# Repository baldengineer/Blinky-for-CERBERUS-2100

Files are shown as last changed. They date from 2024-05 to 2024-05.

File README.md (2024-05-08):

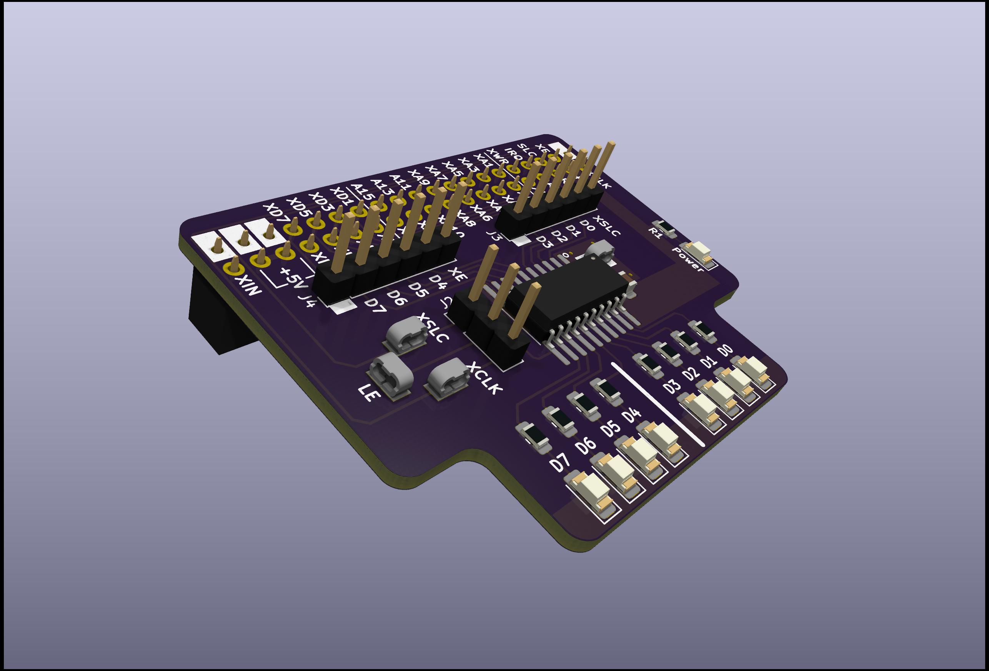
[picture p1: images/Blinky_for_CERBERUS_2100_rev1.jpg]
Blinky Render


## Blinky for CERBERUS 2100
Simple board to plug into a [CERBERUS 2100](https://www.thebyteattic.com/p/cerberus-2100.html) and display blinky patterns. It uses a transparent latch (74HVC573) to display the 8-bit data bus on individual LEDs. You can select between the `XCLK` or `XSLC` to drive the display.

The idea is that `XCLK` would continously update with whatever values are on the data bus. Using `XSLC` should only update after a write occurs (but the timing might be off?).

## Future ideas
I may implement a version with a PLD to experiement with programmable logic. 

## Status
Sent rev 1 to the fab. I realize after that I did not provide an easy way to enable the `XE` signal, which turns on the buffers on the CERBERUS 2100. However, there are pads to bodge it.

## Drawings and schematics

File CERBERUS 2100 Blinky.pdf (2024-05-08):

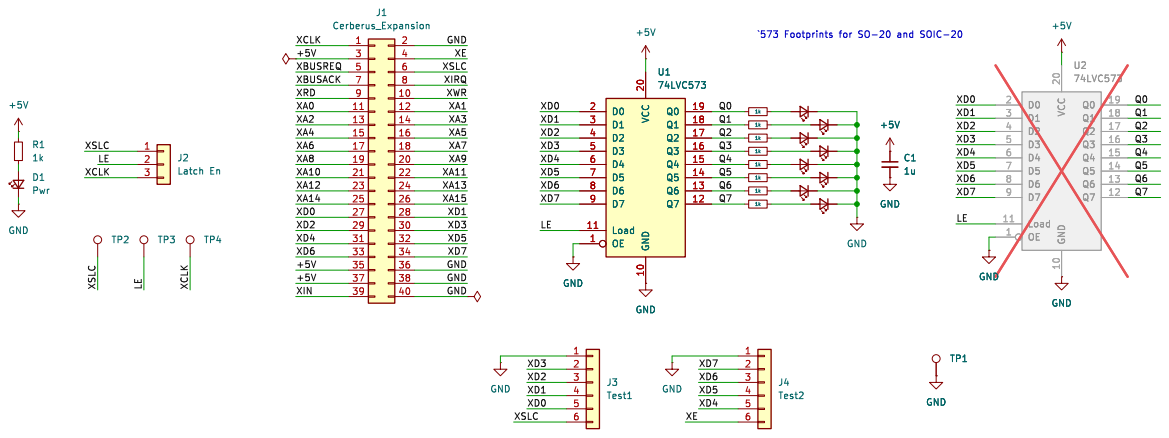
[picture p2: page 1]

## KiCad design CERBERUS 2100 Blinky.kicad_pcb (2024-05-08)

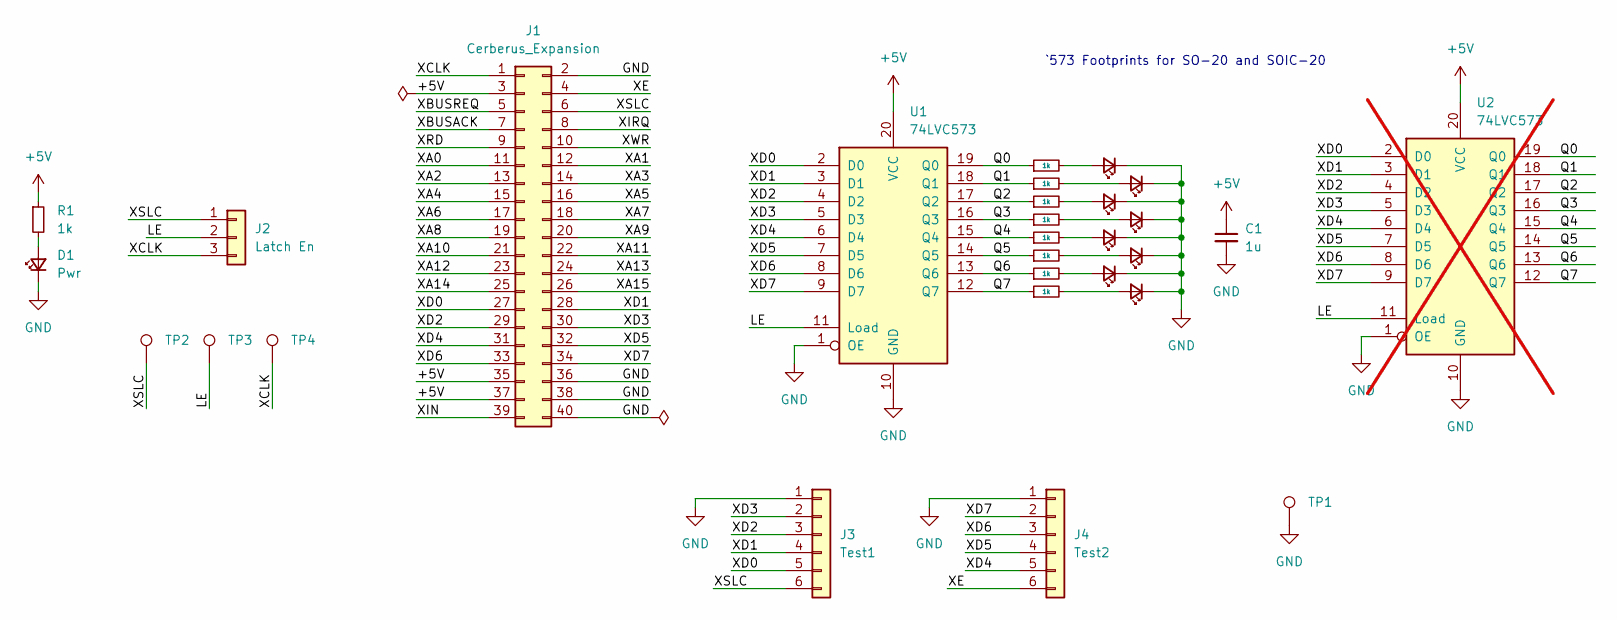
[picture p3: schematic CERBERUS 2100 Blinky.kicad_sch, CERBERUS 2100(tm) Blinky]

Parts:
C1: 1u; C_0805_2012Metric_Pad1.18x1.45mm_HandSolder
D1, D2, D3, D4, D5, D6, D7, D8, D9: Pwr; LED_1206_3216Metric_Pad1.42x1.75mm_HandSolder
J1: Cerberus_Expansion; PinSocket_2x20_P2.54mm_Vertical
J2: Latch En; PinHeader_1x03_P2.54mm_Vertical
J3: Test1; PinHeader_1x06_P2.54mm_Vertical
J4: Test2; PinHeader_1x06_P2.54mm_Vertical
R1, R2, R3, R4, R5, R6, R7, R8, R9: 1k; R_0805_2012Metric_Pad1.20x1.40mm_HandSolder
TP1, TP2, TP3, TP4: TestPoint_Harwin; Harwin-S1751-46-Test-Point
U1: 74LVC573; SO-20_5.3x12.6mm_P1.27mm
U2: 74LVC573; SOIC-20W_7.5x12.8mm_P1.27mm; not fitted

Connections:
+5V: C1.1, J1.3, J1.35, J1.37, R1.1, U1.20 (VCC), U2.20 (VCC)
/LE: J2.2, TP3.1, U1.11 (Load), U2.11 (Load)
/Q0: R2.1, U1.19 (Q0), U2.19 (Q0)
/Q1: R3.1, U1.18 (Q1), U2.18 (Q1)
/Q2: R4.1, U1.17 (Q2), U2.17 (Q2)
/Q3: R5.1, U1.16 (Q3), U2.16 (Q3)
/Q4: R6.1, U1.15 (Q4), U2.15 (Q4)
/Q5: R7.1, U1.14 (Q5), U2.14 (Q5)
/Q6: R8.1, U1.13 (Q6), U2.13 (Q6)
/Q7: R9.1, U1.12 (Q7), U2.12 (Q7)
/XA0: J1.11
/XA1: J1.12
/XA2: J1.13
/XA3: J1.14
/XA4: J1.15
/XA5: J1.16
/XA6: J1.17
/XA7: J1.18
/XA8: J1.19
/XA9: J1.20
/XA10: J1.21
/XA11: J1.22
/XA12: J1.23
/XA13: J1.24
/XA14: J1.25
/XA15: J1.26
/XBUSACK: J1.7
/XBUSREQ: J1.5
/XCLK: J1.1, J2.3, TP4.1
/XD0: J1.27, J3.5, U1.2 (D0), U2.2 (D0)
/XD1: J1.28, J3.4, U1.3 (D1), U2.3 (D1)
/XD2: J1.29, J3.3, U1.4 (D2), U2.4 (D2)
/XD3: J1.30, J3.2, U1.5 (D3), U2.5 (D3)
/XD4: J1.31, J4.5, U1.6 (D4), U2.6 (D4)
/XD5: J1.32, J4.4, U1.7 (D5), U2.7 (D5)
/XD6: J1.33, J4.3, U1.8 (D6), U2.8 (D6)
/XD7: J1.34, J4.2, U1.9 (D7), U2.9 (D7)
/XE: J1.4, J4.6
/XIN: J1.39
/XIRQ: J1.8
/XRD: J1.9
/XSLC: J1.6, J2.1, J3.6, TP2.1
/XWR: J1.10
GND: C1.2, D1.1 (K), D2.1 (K), D3.1 (K), D4.1 (K), D5.1 (K), D6.1 (K), D7.1 (K), D8.1 (K), D9.1 (K), J1.2, J1.36, J1.38, J1.40, J3.1, J4.1, TP1.1, U1.1 (OE), U1.10 (GND), U2.1 (OE), U2.10 (GND)
unnamed: D1.2 (A), R1.2
unnamed: D2.2 (A), R2.2
unnamed: D3.2 (A), R3.2
unnamed: D4.2 (A), R4.2
unnamed: D5.2 (A), R5.2
unnamed: D6.2 (A), R6.2
unnamed: D7.2 (A), R7.2
unnamed: D8.2 (A), R8.2
unnamed: D9.2 (A), R9.2

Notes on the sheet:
`573 Footprints for SO-20 and SOIC-20

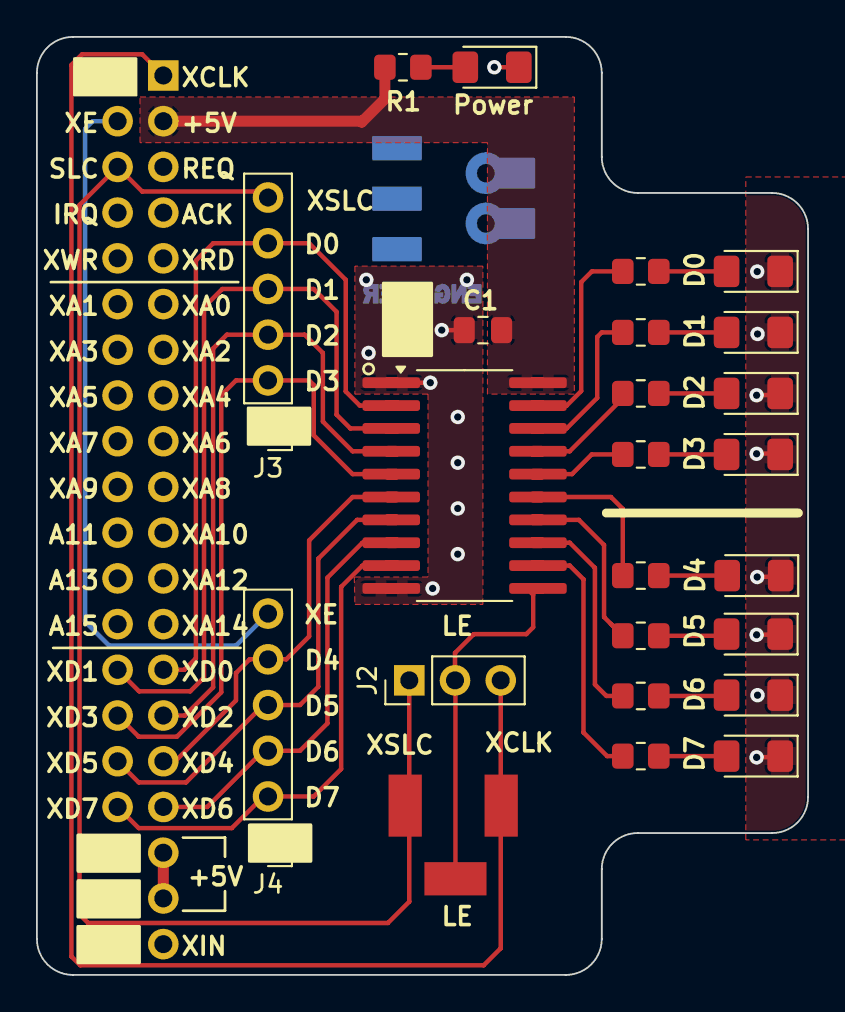
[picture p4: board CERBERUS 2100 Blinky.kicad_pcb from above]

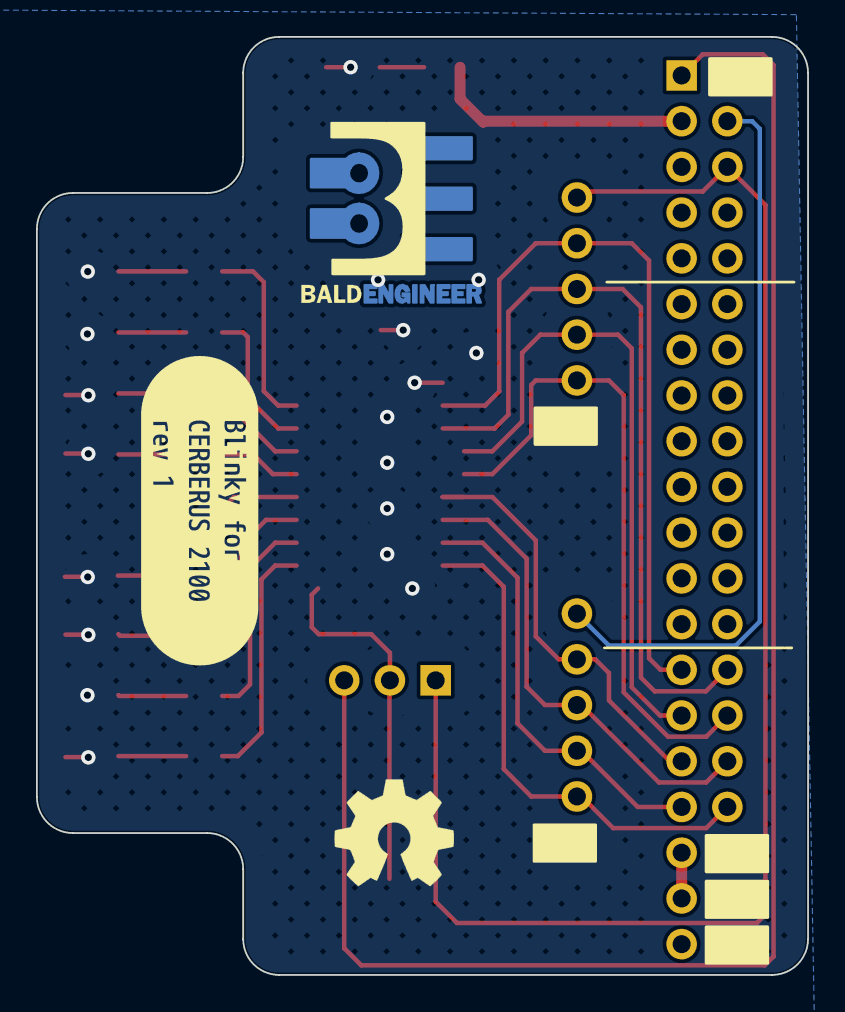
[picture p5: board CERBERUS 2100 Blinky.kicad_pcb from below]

Board: 2 copper layers, 42.8 x 52.1 mm, 31 parts (2 on the bottom side), 31 nets.

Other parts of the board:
kibuzzard-663A818A: G***; kibuzzard-663A818A
svg2mod: G***; BE10v2
